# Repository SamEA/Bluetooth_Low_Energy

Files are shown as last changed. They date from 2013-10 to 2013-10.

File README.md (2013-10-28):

Bluetooth_Low_Energy
====================

Bluetooth 4.0 Low Energy (BLE)

The Bluetooth Board is a breakout board for HM-10 BLE module powered by a TI CC2540. 
It is full programmable with CC-Debugger or SmartRF04EB.

Info about the BLE module can be found here: http://www.jnhuamao.cn/

HM-10 Datasheet can be downloaded from here:  http://www.jnhuamao.cn/bluetooth40_en.rar

Info about the famous CC2540 can be found on TI website http://www.ti.com/product/cc2540&DCMP=LowPowerRFICs+Other&HQS=Other+OT+cc2540

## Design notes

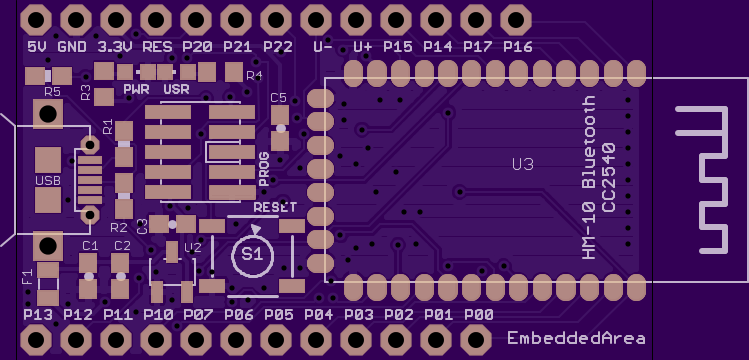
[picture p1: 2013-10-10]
Bluetooth Board (top).png

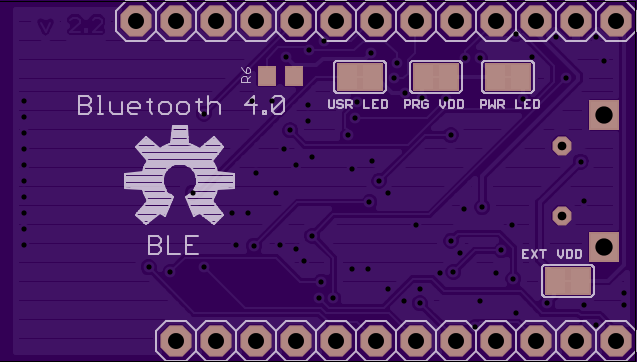
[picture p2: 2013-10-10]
Bluetooth Board (bottom).png

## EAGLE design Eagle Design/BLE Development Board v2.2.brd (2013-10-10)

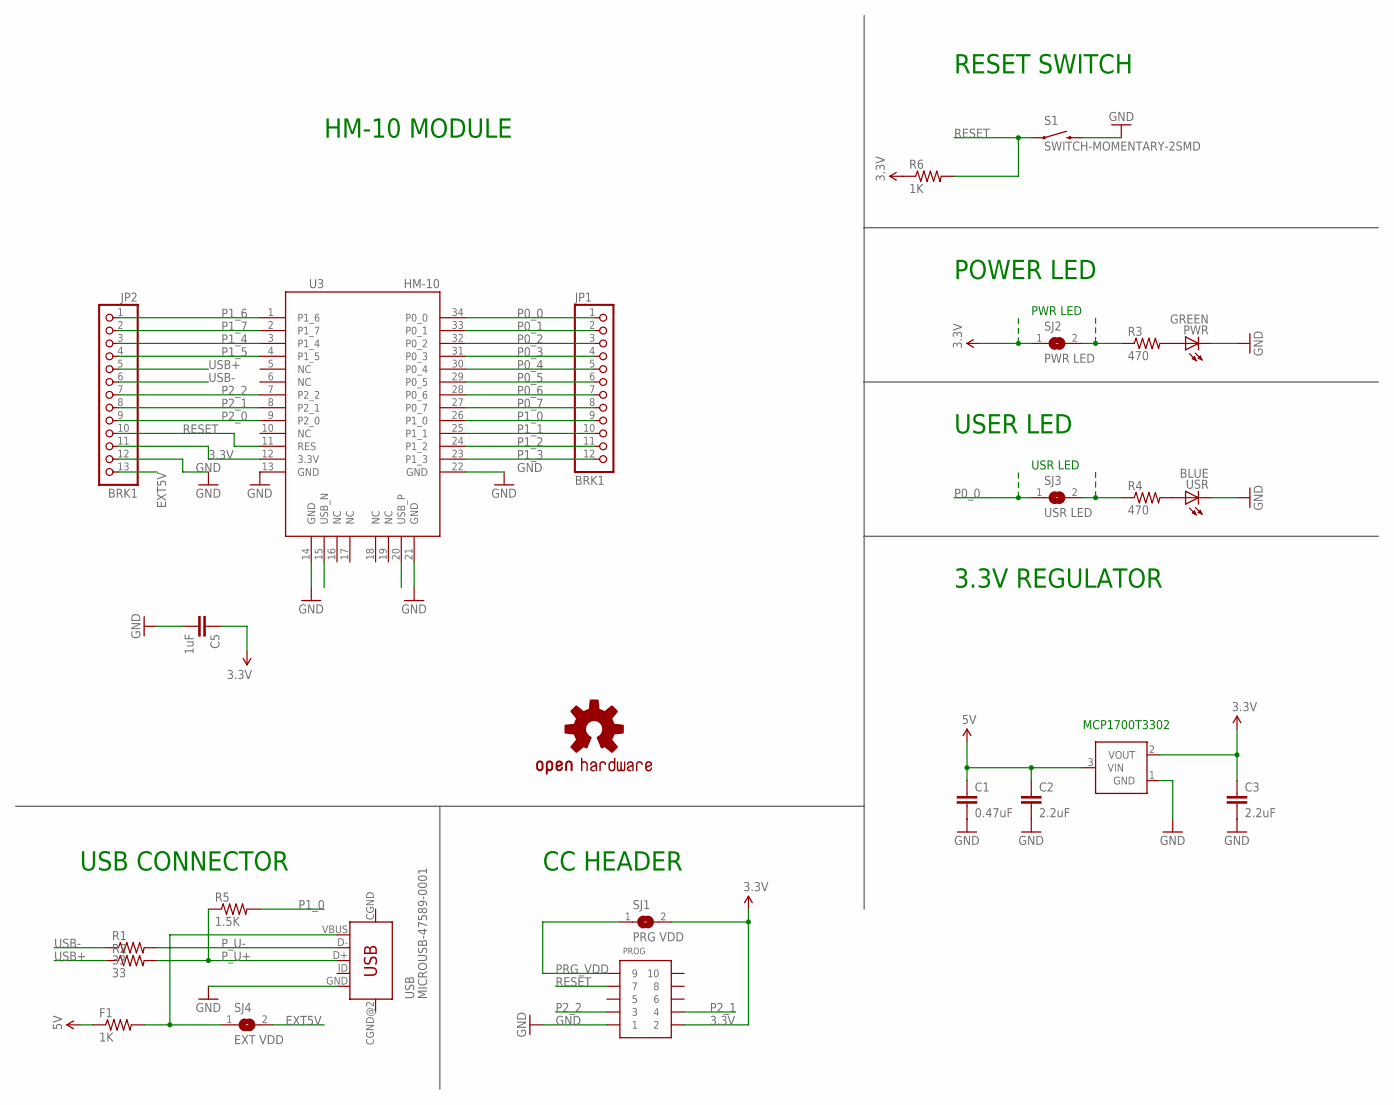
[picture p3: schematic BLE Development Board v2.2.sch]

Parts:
C1: 0.47uF; 0603-CAP
C2, C3: 2.2uF; 0603-CAP
C5: 1uF; 0603-CAP
F1: 1K; 0805
JP1: BRK1; 1X12
JP2: BRK1; 1X13
OSHW1: OSHW-LOGOL; OSHW-LOGO-L
PROG: CONN_5-2-FTSH-V; FTSH-105-DV
PWR: GREEN; CHIPLED_0603
R1, R2: 33; 0603-RES
R3, R4: 470; R0603
R5: 1.5K; 0603-RES
R6: 1K; R0603
S1: SWITCH-MOMENTARY-2SMD; TACTILE_SWITCH_SMD
SJ1: PRG VDD; SJ
SJ2: PWR LED; SJ
SJ3: USR LED; SJ
SJ4: EXT VDD; SJ
U2: MCP1700; SOT23-3
U3: HM-10
USB: MICROUSB-47589-0001
USR: BLUE; CHIPLED_0603

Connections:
3.3V: C3.1, C5.1, JP2.11, PROG.2, R6.1, SJ1.2, SJ2.1, U2.2 (VOUT), U3.12 (3.3V)
5V: C1.1, C2.1, F1.1, U2.3 (VIN)
EXT5V: JP2.13, SJ4.2
GND: C1.2, C2.2, C3.2, C5.2, JP2.12, PROG.1, PWR.C, S1.3 (2), U2.1 (GND), U3.13 (GND), U3.14 (GND), U3.21 (GND), U3.22 (GND), USB.GND, USR.C
unnamed: PWR.A, R3.2
unnamed: R3.1, SJ2.2
unnamed: R4.2, USR.A
unnamed: R4.1, SJ3.2
P0_0: JP1.1, SJ3.1, U3.34 (P0_0)
P0_1: JP1.2, U3.33 (P0_1)
P0_2: JP1.3, U3.32 (P0_2)
P0_3: JP1.4, U3.31 (P0_3)
P0_4: JP1.5, U3.30 (P0_4)
P0_5: JP1.6, U3.29 (P0_5)
P0_6: JP1.7, U3.28 (P0_6)
P0_7: JP1.8, U3.27 (P0_7)
P1_0: JP1.9, R5.2, U3.26 (P1_0)
P1_1: JP1.10, U3.25 (P1_1)
P1_2: JP1.11, U3.24 (P1_2)
P1_3: JP1.12, U3.23 (P1_3)
P1_4: JP2.3, U3.3 (P1_4)
P1_5: JP2.4, U3.4 (P1_5)
P1_6: JP2.1, U3.1 (P1_6)
P1_7: JP2.2, U3.2 (P1_7)
P2_0: JP2.9, U3.9 (P2_0)
P2_1: JP2.8, PROG.4, U3.8 (P2_1)
P2_2: JP2.7, PROG.3, U3.7 (P2_2)
PRG_VDD: PROG.9, SJ1.1
P_U+: R2.2, R5.1, USB.D+
P_U-: R1.2, USB.D-
RESET: JP2.10, PROG.7, R6.2, S1.1, U3.11 (RES)
USB+: JP2.5, R2.1, U3.20 (USB_P)
USB-: JP2.6, R1.1, U3.15 (USB_N)
VBUS: F1.2, SJ4.1, USB.VBUS

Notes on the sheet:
PWR LED
USR LED
POWER LED
USER LED
USB CONNECTOR
CC HEADER
HM-10 MODULE
3.3V REGULATOR
RESET SWITCH
MCP1700T3302

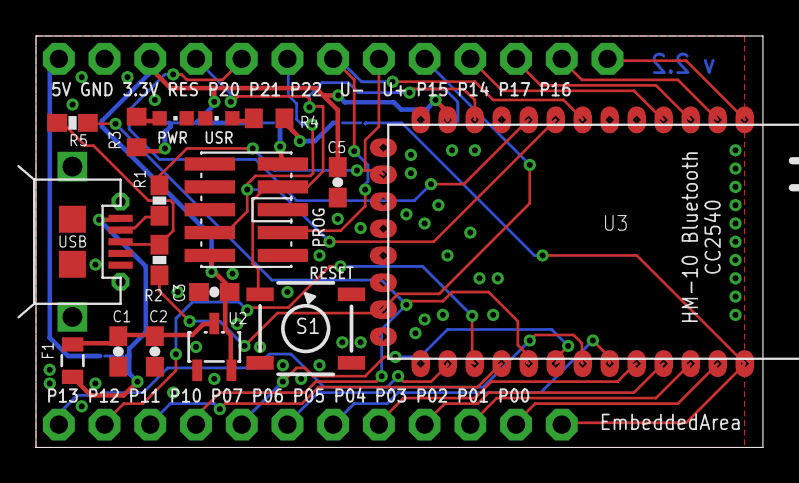
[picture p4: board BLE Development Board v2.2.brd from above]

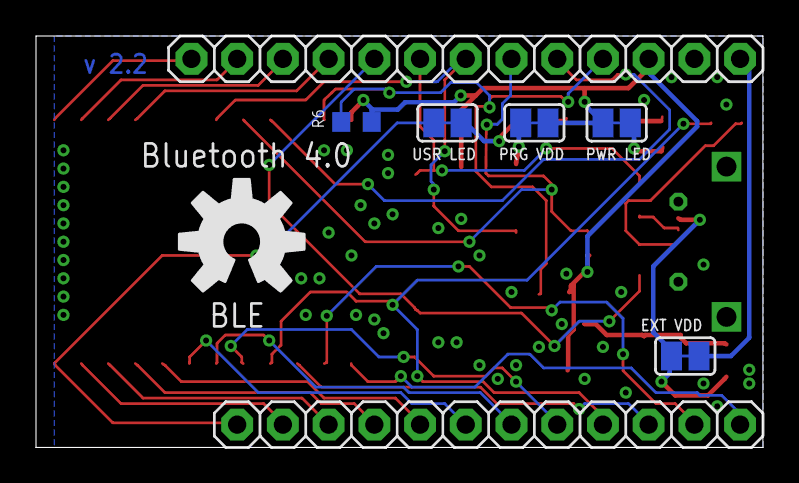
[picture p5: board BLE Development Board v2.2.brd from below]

Board: 2 copper layers, 40.4 x 22.9 mm, 25 parts (8 on the bottom side), 34 nets.

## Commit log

2013-10-03 New Development Board
    [BLE Development Board v2.1.brd, BLE Development Board v2.1.sch]
2013-10-06 improved version
    [BLE Development Board v2.1.brd, BLE Development Board v2.1.sch]
2013-10-10 Fixed Power/Reset issue.
    Fixed Power and Reset issue. Added a pull-up resistor on reset pin.
    [BLE Development Board v2.2.brd, BLE Development Board v2.2.sch]

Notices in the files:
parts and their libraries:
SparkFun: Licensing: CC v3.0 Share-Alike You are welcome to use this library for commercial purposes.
